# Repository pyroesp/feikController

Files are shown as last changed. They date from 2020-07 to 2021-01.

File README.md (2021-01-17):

# feikController

feikController is a PIC16F18325 emulating a PlayStation 1 controller.  
I wanted to make this into a library but it's too device specific.    

## Disclaimer

This has been tested on my PlayStation 1 and it seems to be working fine.  
However, I am not responsible if for some reason your PlayStation gets damaged by using or installing this.  

You use this at your own risk.  

## Why

The original idea for feikController came from the fact you can use a second controller to play Time Crisis.  
You can use that second controller to hide/reload by pressing on the buttons with your foot, so it's just like the pedal button on the arcade games.  

I recently made the PlayStation 1 reset mod with the 16F18325 so I was confident I could emulate a controller.  

## Pedal project

The pedal project uses a pedal button to send an X button press to the PlayStation.  
Here's a demo of the pedal controller :  
Demo PlayStation pedal controller (https://www.youtube.com/watch?v=5PXXQ49MqOc)

You can find [a playlist](https://www.youtube.com/watch?v=J5fQKmc8AMY&list=PLGaX4WJGgdHhcbQUQQJR6zFgzyka-xVOa) of me struggling to make this pedal controller.  
  
Take a look at the source if you want to learn more about it. I've tried to add comments to the code.  

I'd like to point out that the code as it is now is overkill for just a pedal that only works for Time Crisis.  
**It's more a proof of concept on making a PlayStation 1 controller.**  

I also made it so you can use either normal open or normal close button with the pedal. You just need to change the button defines a bit, see the source files.

**Note:** You could very well use this 

## Schematic and PCB

The schematic and PCB is pretty much the same as the reset mod I did for the PlayStation 1, just a few changes and more pads for the button.  

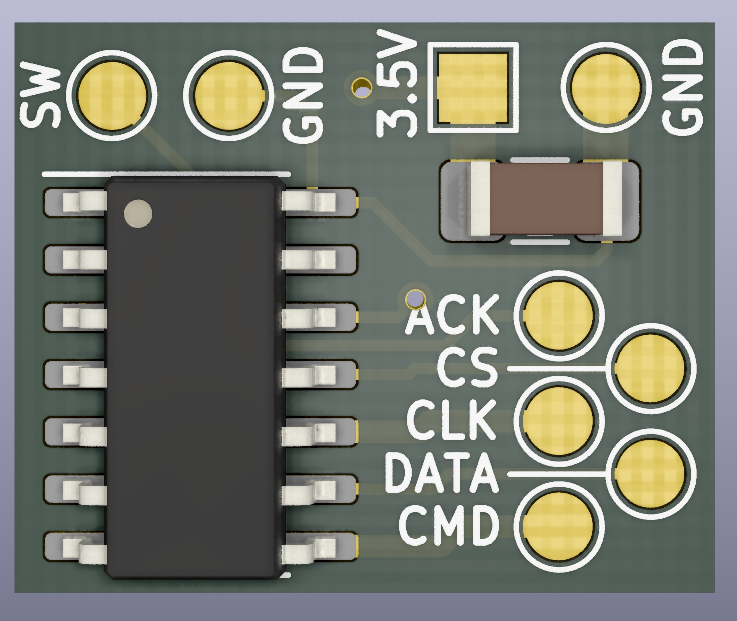
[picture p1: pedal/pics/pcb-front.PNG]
PlayStation pedal pcb front
  
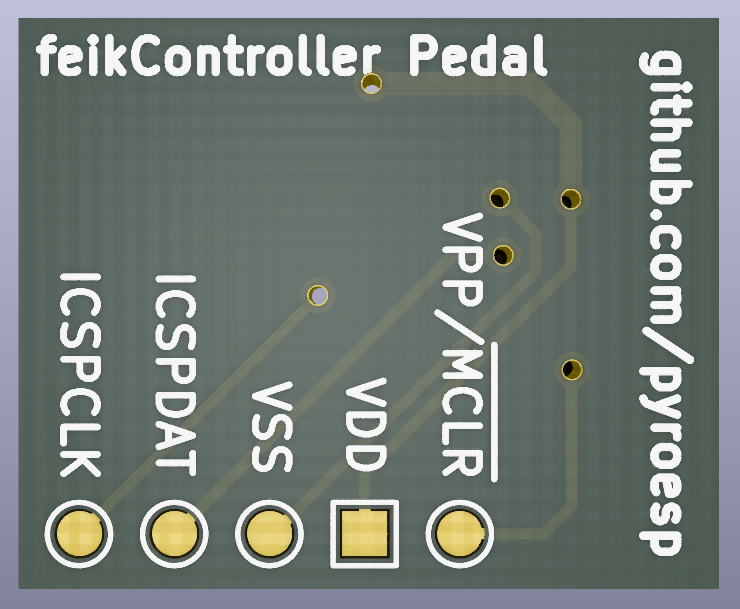
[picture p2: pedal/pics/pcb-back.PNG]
PlayStation pedal pcb back
  
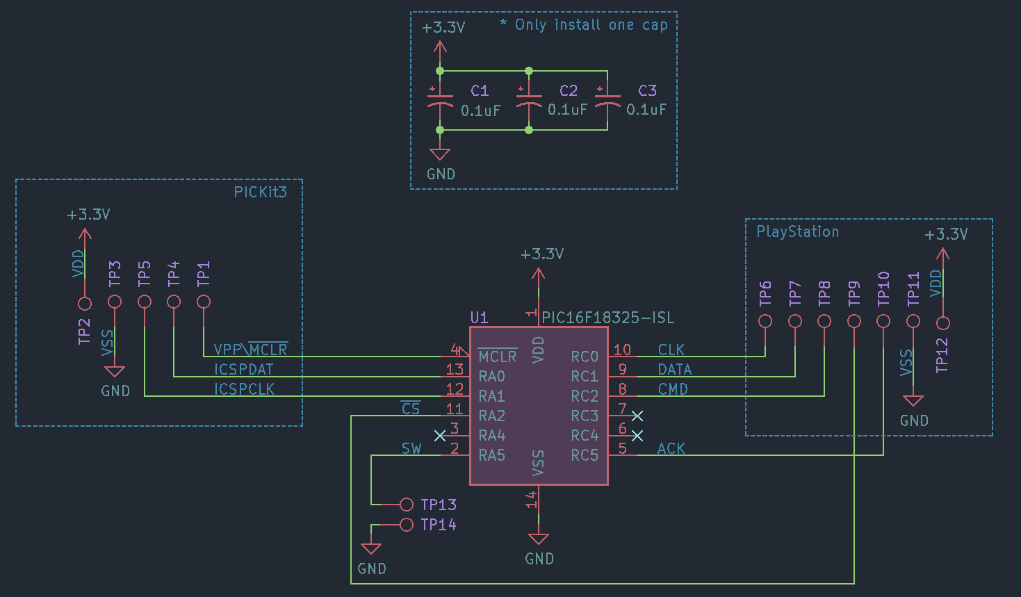
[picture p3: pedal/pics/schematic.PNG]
PlayStation pedal schematic
  

## License

Attribution-ShareAlike 4.0 International, see license file for more info

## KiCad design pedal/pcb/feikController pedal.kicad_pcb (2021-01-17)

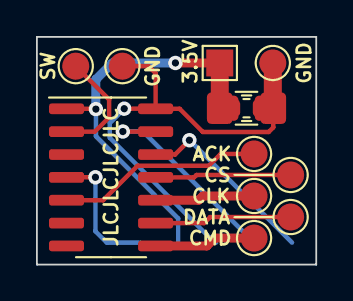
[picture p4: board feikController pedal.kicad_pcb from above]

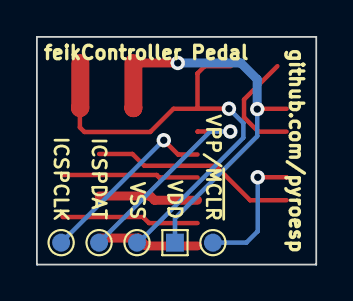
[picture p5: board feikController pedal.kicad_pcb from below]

Board: 2 copper layers, 15.5 x 12.6 mm, 18 parts (5 on the bottom side), 11 nets.

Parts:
3.5V: TestPoint; TestPoint_Pad_1.5x1.5mm
ACK: TestPoint; TestPoint_Pad_D1.5mm
C1: 0.1uF; C_1206_3216Metric_Pad1.42x1.75mm_HandSolder
C2: 0.1uF; C_0805_2012Metric_Pad1.15x1.40mm_HandSolder
C3: 0.1uF; C_0603_1608Metric_Pad1.05x0.95mm_HandSolder
CLK: TestPoint; TestPoint_Pad_D1.5mm
CMD: TestPoint; TestPoint_Pad_D1.5mm
CS: TestPoint; TestPoint_Pad_D1.5mm
DATA: TestPoint; TestPoint_Pad_D1.5mm
GND: TestPoint; TestPoint_Pad_D1.5mm
GND#2: TestPoint; TestPoint_Pad_D1.5mm
ICSPCLK: TestPoint; TestPoint_Pad_D1.0mm
ICSPDAT: TestPoint; TestPoint_Pad_D1.0mm
SW: TestPoint; TestPoint_Pad_D1.5mm
U1: PIC16F18325-ISL; SOIC-14_3.9x8.7mm_P1.27mm
VDD: TestPoint; TestPoint_Pad_1.0x1.0mm
VPP/~MCLR: TestPoint; TestPoint_Pad_D1.0mm
VSS: TestPoint; TestPoint_Pad_D1.0mm

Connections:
+3V3: 3.5V.1, C1.1, C2.1, C3.1, U1.1, VDD.1
/ACK: ACK.1, U1.5
/CLK: CLK.1, U1.10
/CMD: CMD.1, U1.8
/DATA: DATA.1, U1.9
/ICSPCLK: ICSPCLK.1, U1.12
/ICSPDAT: ICSPDAT.1, U1.13
/SW: SW.1, U1.2
/VPP\~MCLR: U1.4, VPP/~MCLR.1
/~SS: CS.1, U1.11
GND: C1.2, C2.2, C3.2, GND.1, GND#2.1, U1.14, VSS.1

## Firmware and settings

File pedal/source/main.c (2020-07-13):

/* 
 * File:   main.c
 * Author: pyroesp
 * Project: Pedal Switch Controller PS1
 * Created on: May 20, 2020, 3:41 PM
 */


#include "pic_config.h"

/** Freq Definition **/
#define _XTAL_FREQ 32000000

/** Includes **/
#include <xc.h>
#include <stdint.h>

#include "playstation.h"
#include "pedal.h"

/*
 Connection:
    RA2 = /SS
    RC0 = CLK
    RC1 = DATA (SDO1)
    RC2 = CMD (SDI1)

    RA5 = Pedal Switch
    RC5 = /ACK
*/

#define CLR_BIT(v,b) ((v) &= ~(1 << (b)))
#define SET_BIT(v,b) ((v) |= 1 << (b))
#define GET_BIT(v,b) (!!((v) & (1 << (b))))

/* Global variables */
volatile union PS1_Cmd cmd;
volatile union PS1_Ctrl_Data data;
volatile uint8_t cnt;
volatile uint8_t send_ack;
volatile uint8_t memcard_spi;

/** Reverse byte order **/
void _reverseByte(volatile uint8_t *b);

/* Interrupt */
void __interrupt() _spi_int(void) {
    uint8_t temp_spi;
    // SPI1 interrupt
    if (PIR1bits.SSP1IF){
        // Copy received SPI byte into temp variable
        temp_spi = SSP1BUF;
        _reverseByte(&temp_spi);
        /*
         * Reset the SSP1BUF so SDO is always high whenever the PlayStation
         * reads data from the memory card
         */
        // If the SPI byte is the first one
        if (cnt == 0){
            // Write first SPI byte into the cmd device select
            cmd.device_select = temp_spi;
            cnt++;
        }
        /*
         * If the device select is the controller byte (01h)
         * output data to the PlayStation.
         * The cnt counter will be reset when SS is high.
         *
         * If the device select is the memory card byte (81h),
         * all received bytes will be ignored
         */
        SSP1BUF = 0xFF; // clear output
        if (cmd.device_select == CONTROLLER_SEL){
            if (cnt < PS1_CTRL_BUFF_SIZE){
                temp_spi = data.buff[cnt];
                _reverseByte(&temp_spi);
                SSP1BUF = temp_spi;
                cnt++;
                send_ack = 1;
            }
        }else{ // If PlayStation is trying to read the memory card
            SSP1CON1bits.SSPEN = 0; // disable SPI1
            TRISCbits.TRISC1 = 1; // SDO1 set to input
            memcard_spi = 1;
        }
        PIR1bits.SSP1IF = 0; // clear SPI1 flag
    }
}


void main(){    
    // Setup PlayStation structure
    cmd.device_select = 0x00;
    cmd.command = 0x00;
    data.unused1 = 0xFF;
    data.unused2 = 0xFF;
    data.id_hi = CONTROLLER_IDHI;
    data.id_lo = CONTROLLER_IDLO;
    data.keys_hi = CONTROLLER_BUTTON_RESET;
    data.keys_lo = CONTROLLER_BUTTON_RESET;
    cnt = 0;
    send_ack = 0;
    
    /* Configure IO for the pedal */
    CLR_BIT(PEDAL_ANSEL, PEDAL_INPUT); // Set to digital IO
    SET_BIT(PEDAL_TRIS, PEDAL_INPUT); // Set to input
#ifdef PEDAL_PULL_UP
    SET_BIT(PEDAL_PULL_UP, PEDAL_INPUT); // Enable pull-up
#endif
    
    /* Configure IO for the ACK signal */
    CLR_BIT(ACK_ANSEL, ACK_OUTPUT); // Set to digital IO
    SET_BIT(ACK_TRIS, ACK_OUTPUT); // Set to input
    CLR_BIT(ACK_LAT, ACK_OUTPUT); // Set output latch low
    
    LATA = 0; // clear output latch port A
    LATC = 0; // clear output latch port C

    ANSELAbits.ANSA2 = 0; // set to IO
    TRISAbits.TRISA2 = 1; // SS set to input
    ANSELCbits.ANSC0 = 0; // set to IO
    TRISCbits.TRISC0 = 1; // SCK set to input
    ANSELCbits.ANSC2 = 0; // set to IO
    TRISCbits.TRISC2 = 1; // SDI1 set to input
    ANSELCbits.ANSC1 = 0; // set to IO
    TRISCbits.TRISC1 = 0; // SDO1 set to output

    // SETUP SPI1 I/O
    SSP1CLKPPSbits.SSP1CLKPPS = 0x10; // SCK1 = RC0
    SSP1SSPPSbits.SSP1SSPPS = 0x02; // SS1 = RA2
    SSP1DATPPSbits.SSP1DATPPS = 0x12; // SDI1 = RC2
    RC1PPS = 0x19; // SDO1 = RC1

    // SETUP SPI1
    SSP1STATbits.SMP = 0; // slave mode SPI1
    SSP1STATbits.CKE = 0;
    SSP1CON1bits.CKP = 1; // clock idle high
    SSP1CON1bits.SSPM = 0x04; // slave mode: CLK = SCK pin; SS enabled
    SSP1CON3bits.BOEN = 1; // ignore BF flag
    SSP1CON1bits.SSPEN = 1; // enable SPI1

    SSP1BUF = 0xFF;
    
    /* Enable interrupts */
    PIR1bits.SSP1IF = 0; // clear SPI1 flag
    PIE1bits.SSP1IE = 1; // enable MSSP interrupt (SPI1)

    INTCONbits.PEIE = 1; // peripheral interrupt enable
    INTCONbits.GIE = 1; // global interrupt enable
        
    while(1){

        // Send Ack to PlayStation
        if (send_ack){
            // Set the ACK pin to an output, LAT already to 0
            CLR_BIT(ACK_TRIS, ACK_OUTPUT);
            NOP(); // 125ns
            NOP(); // 125ns
            NOP(); // 125ns
            NOP(); // 125ns - 500ns
            NOP(); // 125ns
            NOP(); // 125ns
            NOP(); // 125ns
            NOP(); // 125ns - 1us
            NOP(); // 125ns
            NOP(); // 125ns
            NOP(); // 125ns
            NOP(); // 125ns - 1.5us
            NOP(); // 125ns
            NOP(); // 125ns
            NOP(); // 125ns
            NOP(); // 125ns - 2us
            NOP(); // 125ns
            NOP(); // 125ns
            NOP(); // 125ns
            NOP(); // 125ns - 2.5us
            SET_BIT(ACK_TRIS, ACK_OUTPUT); // Set ACK pin back to input
            send_ack = 0;
        }
        
        // Reset counter whenever SS is high
        if (PORTAbits.RA2 == 1){
            memcard_spi = 0; // when SS high, communication done so reset the variable
            if (SSP1CON1bits.SSPEN){ // if SS high and SPI enabled
                SSP1CON1bits.SSPEN = 0; // disable SPI1
            }
        }else{
            // if SS low and SPI disabled and PlayStation isn't reading the memory card anymore
            if (!SSP1CON1bits.SSPEN && !memcard_spi){ 
                cnt = 0; // reset counter
                SSP1BUF = 0xFF; // clear SPI buffer content
                TRISCbits.TRISC1 = 0; // SDO1 set to output
                SSP1CON1bits.SSPEN = 1; // enable SPI1
            }
        }
        
        // Read pedal switch status
        if (GET_BIT(PEDAL_PORT, PEDAL_INPUT) != PEDAL_BUTTON_MODE){
            #if (PEDAL_BUTTON > 7)
                CLR_BIT(data.keys_hi, (PEDAL_BUTTON - 8));
            #else
                CLR_BIT(data.keys_lo, PEDAL_BUTTON);
            #endif
        }else{
                data.keys_hi = CONTROLLER_BUTTON_RESET;
                data.keys_lo = CONTROLLER_BUTTON_RESET;
        }
    }
    
    for(;;);
}

/*
 * Reverse byte order
 * The PlayStation send data LSb first,
 * but the PIC uses a shift right register
 * so the LSb from the PS1 becomes the MSb of the PIC
 */
void _reverseByte(volatile uint8_t *b){
    *b = (*b & 0xF0) >> 4 | (*b & 0x0F) << 4;
    *b = (*b & 0xCC) >> 2 | (*b & 0x33) << 2;
    *b = (*b & 0xAA) >> 1 | (*b & 0x55) << 1;
}

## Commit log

2020-07-05 moved ACK delay from interrupt and into main loop
2020-07-05 fixed the code to not have to use a transistor on the DATA line
    [main.c]
2020-07-13 updated code with bugfix and put in folder
    [main.c]
2020-07-13 add gitignore to kicad project folder
2020-07-13 first commit kicad project
    [feikController pedal.kicad_pcb, feikController pedal.sch]
2020-12-26 updated schematic/PCB/gerber + added pics
    [feikController pedal-B_Cu.gbr, feikController pedal-B_Mask.gbr, feikController pedal-B_SilkS.gbr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]
2021-01-17 general update/cleanup
    [feikController pedal-B_Cu.gbr, feikController pedal-B_Mask.gbr, feikController pedal-B_SilkS.gbr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]
